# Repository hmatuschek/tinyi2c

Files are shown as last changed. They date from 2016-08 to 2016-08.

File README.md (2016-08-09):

# tiny-i2c -- An augmented i2c-tiny-usb compatible device emulating various I2C devices.

This tiny USB device provides an I2C interface based on the original [i2c-tiny-usb](http://www.harbaum.org/till/i2c_tiny_usb/index.shtml) device. Hence, it is supported by the Linux kernel. Additionally, it is able to emulate various I2C devices in firmware. For example, it is able to emulate the [LM90](http://www.ti.com/product/LM90) temperature sensor by using a simple NTC resistor as a temperature sensor and the build-in temperature sensor of the [ATTiny45](http://www.atmel.com/images/atmel-2586-avr-8-bit-microcontroller-attiny25-attiny45-attiny85_datasheet.pdf).

## License
tinyi2c - Copyright (C) 2016 Hannes Matuschek

This program is free software; you can redistribute it and/or modify it under the terms of the GNU General Public License as published by the Free Software Foundation; either version 2 of the License, or (at your option) any later version.

This program is distributed in the hope that it will be useful, but WITHOUT ANY WARRANTY; without even the implied warranty of MERCHANTABILITY or FITNESS FOR A PARTICULAR PURPOSE. See the GNU General Public License for more details.

You should have received a copy of the GNU General Public License along with this program; if not, write to the Free Software Foundation, Inc., 51 Franklin Street, Fifth Floor, Boston, MA 02110-1301, USA.

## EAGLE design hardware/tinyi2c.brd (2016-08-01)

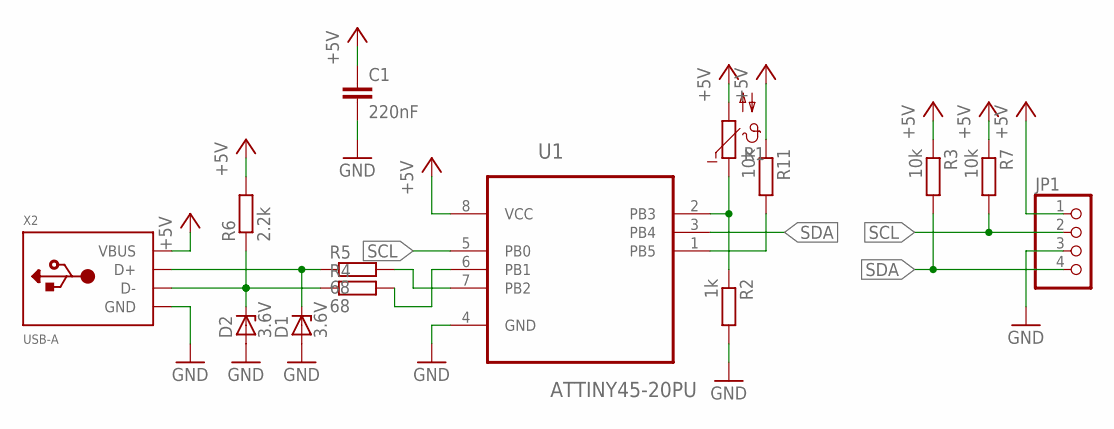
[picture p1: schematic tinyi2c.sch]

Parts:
C1: 220nF; C075-032X103
D1: 3.6V; ZDIO-2.5
D2: 3.6V; ZDIO-5
JP1: PINHD-1X4; 1X04
R1: B57164
R2: 1k; 0207/10
R3: 10k; 0207/10
R4, R5: 68; 0204/5
R6: 2.2k; 0204V
R7: 10k; 0204V
R11: 10k; 0204/7
U1: ATTINY45-20PU; DIP254P762X533-8
X2: USB-A; MOLEX_480371000

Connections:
+5V: C1.1, JP1.1, R1.2, R3.1, R6.2, R7.1, R11.1, U1.8 (VCC), X2.1 (VBUS)
GND: C1.2, D1.A, D2.A, JP1.3, R2.2, U1.4 (GND), X2.4 (GND)
unnamed: R1.1, R2.1, U1.2 (PB3)
unnamed: R4.2, U1.6 (PB1)
unnamed: R5.2, U1.7 (PB2)
unnamed: R11.2, U1.1 (PB5)
unnamed: D1.C, R5.1, X2.3 (D+)
unnamed: D2.C, R4.1, R6.1, X2.2 (D-)
SCL: JP1.2, R7.2, U1.5 (PB0)
SDA: JP1.4, R3.2, U1.3 (PB4)

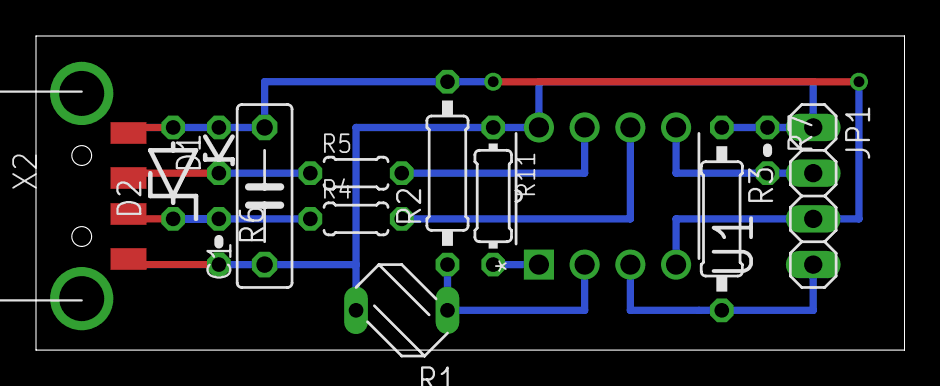
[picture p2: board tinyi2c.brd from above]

Board: 2 copper layers, 48.2 x 17.5 mm, 14 parts (0 on the bottom side), 10 nets.

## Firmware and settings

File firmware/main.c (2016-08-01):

/* Name: main.c
 * Project: i2c-tiny-usb
 * Author: Till Harbaum
 * Tabsize: 4
 * Copyright: (c) 2005 by Till Harbaum <till@harbaum.org>
 * License: GPL
 * This Revision: $Id: main.c,v 1.9 2007/06/07 13:53:47 harbaum Exp $
 *
 * $Log: main.c,v $
 * Revision 1.9  2007/06/07 13:53:47  harbaum
 * Version number fixes
 *
 * Revision 1.8  2007/05/19 12:30:11  harbaum
 * Updated USB stacks
 *
 * Revision 1.7  2007/04/22 10:34:05  harbaum
 * *** empty log message ***
 *
 * Revision 1.6  2007/01/05 19:30:58  harbaum
 * i2c clock bug fix
 *
 * Revision 1.5  2007/01/03 18:35:07  harbaum
 * usbtiny fixes and pcb layouts
 *
 * Revision 1.4  2006/12/03 21:28:59  harbaum
 * *** empty log message ***
 *
 * Revision 1.3  2006/11/22 19:12:45  harbaum
 * Added usbtiny support
 *
 * Revision 1.2  2006/11/14 19:15:13  harbaum
 * *** empty log message ***
 *
 */

#include <stdio.h>
#include <ctype.h>
#include <string.h>

#include <avr/io.h>
#include <avr/interrupt.h>
#include <avr/pgmspace.h>
#include <avr/eeprom.h>
#include <util/delay.h>

// use avrusb library
#include "usbdrv/usbdrv.h"
#include "smb.h"
#include "ds1621.h"
#include "temp.h"


/* ------------------------------------------------------------------------- */

int	main(void) {
  // Init USB <-> I2C/SMBus interface
  smb_init();
  // init temperature measurement
  temp_init();
  // enable interrupts
  sei();

  // Go!

  for(;;) {	/* main event loop */
    usbPoll();
  }

  return 0;
}

/* ------------------------------------------------------------------------- */

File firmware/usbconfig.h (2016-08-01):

/* Name: usbconfig.h
 * Project: V-USB, virtual USB port for Atmel's(r) AVR(r) microcontrollers
 * Author: Christian Starkjohann
 * Creation Date: 2005-04-01
 * Tabsize: 4
 * Copyright: (c) 2005 by OBJECTIVE DEVELOPMENT Software GmbH
 * License: GNU GPL v2 (see License.txt), GNU GPL v3 or proprietary (CommercialLicense.txt)
 */

#ifndef __usbconfig_h_included__
#define __usbconfig_h_included__

/*
General Description:
This file is an example configuration (with inline documentation) for the USB
driver. It configures V-USB for USB D+ connected to Port D bit 2 (which is
also hardware interrupt 0 on many devices) and USB D- to Port D bit 4. You may
wire the lines to any other port, as long as D+ is also wired to INT0 (or any
other hardware interrupt, as long as it is the highest level interrupt, see
section at the end of this file).
+ To create your own usbconfig.h file, copy this file to your project's
+ firmware source directory) and rename it to "usbconfig.h".
+ Then edit it accordingly.
*/

/* ---------------------------- Hardware Config ---------------------------- */

#define USB_CFG_IOPORTNAME      B
/* This is the port where the USB bus is connected. When you configure it to
 * "B", the registers PORTB, PINB and DDRB will be used.
 */
#define USB_CFG_DMINUS_BIT      1
/* This is the bit number in USB_CFG_IOPORT where the USB D- line is connected.
 * This may be any bit in the port.
 */
#define USB_CFG_DPLUS_BIT       2
/* This is the bit number in USB_CFG_IOPORT where the USB D+ line is connected.
 * This may be any bit in the port. Please note that D+ must also be connected
 * to interrupt pin INT0!
 */
#define USB_CFG_CLOCK_KHZ       (F_CPU/1000)
/* Clock rate of the AVR in MHz. Legal values are 12000, 16000 or 16500.
 * The 16.5 MHz version of the code requires no crystal, it tolerates +/- 1%
 * deviation from the nominal frequency. All other rates require a precision
 * of 2000 ppm and thus a crystal!
 * Default if not specified: 12 MHz
 */
#define USB_CFG_CHECK_CRC       0
/* Define this to 1 if you want that the driver checks integrity of incoming
 * data packets (CRC checks). CRC checks cost quite a bit of code size and are
 * currently only available for 18 MHz crystal clock. You must choose
 * USB_CFG_CLOCK_KHZ = 18000 if you enable this option.
 */

/* ----------------------- Optional Hardware Config ------------------------ */

/* #define USB_CFG_PULLUP_IOPORTNAME   D */
/* If you connect the 1.5k pullup resistor from D- to a port pin instead of
 * V+, you can connect and disconnect the device from firmware by calling
 * the macros usbDeviceConnect() and usbDeviceDisconnect() (see usbdrv.h).
 * This constant defines the port on which the pullup resistor is connected.
 */
/* #define USB_CFG_PULLUP_BIT          4 */
/* This constant defines the bit number in USB_CFG_PULLUP_IOPORT (defined
 * above) where the 1.5k pullup resistor is connected. See description
 * above for details.
 */

/* --------------------------- Functional Range ---------------------------- */
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

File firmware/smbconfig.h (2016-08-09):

/** @file smbconfig.h SMBus config file.
 * This file collects the definitions needed to set up the hardware I2C and virtual SMBus
 * interfaces. */

#ifndef __SMBCONFIG_H__
#define __SMBCONFIG_H__

// IO pins for the I2C HW interface
#define I2C_PORT   PORTB
#define I2C_PIN    PINB
#define I2C_DDR    DDRB
#define I2C_SDA    _BV(4)
#define I2C_SCL    _BV(0)

#include "lm90.h"
#include "ds1621.h"

/// Number of present SMBus hooks.
#define SMB_HOOK_COUNT 2
/// List of SMBus hooks.
#define SMB_HOOKS      LM90_HOOK, DS1621_HOOK

#endif // __SMBCONFIG_H__
